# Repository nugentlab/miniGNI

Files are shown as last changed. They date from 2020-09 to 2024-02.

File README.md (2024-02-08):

## [An updated version of the miniGNI can be found here](https://github.com/klackerman00/miniGNI_plus)
# miniGNI Version 1.0
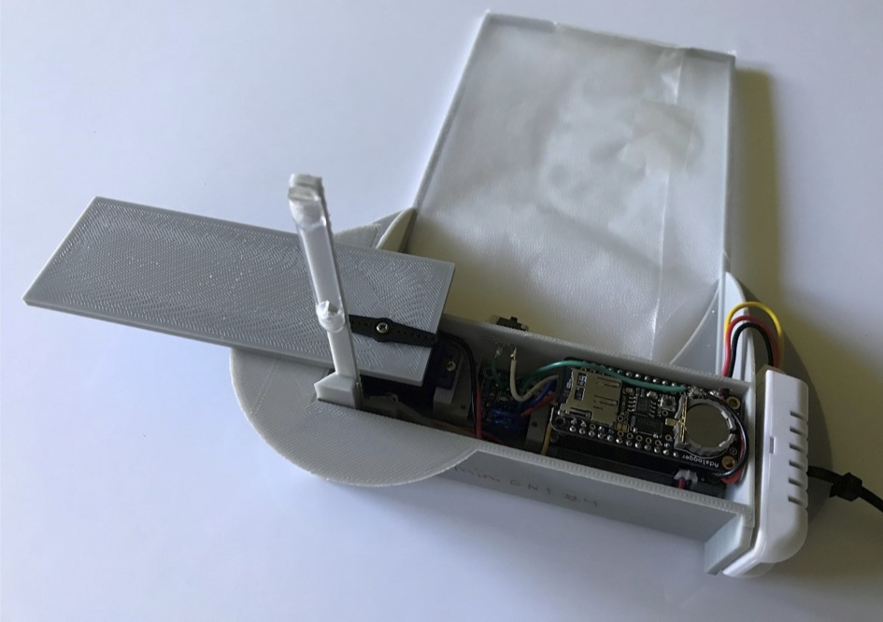
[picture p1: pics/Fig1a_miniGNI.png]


## **mini-GNI** - Miniature Giant Nucleus Impactor 

The mini-GNI is a small, 3D instrumentation created by the [Nugent Research Group](http://alisonnugent.com/) used to sample sea salt aerosol (SSA) aloft using ground-based platforms. Modeled off the [National Center for Atmospheric Research GNI](https://www.eol.ucar.edu/instruments/giant-nuclei-impactor), the mini-GNI combines Arduino based microcontrollers and 3D printed technology in order to expose polycarbonate slides to free airstreams, allowing SSA to impact onto them. Then, these slides are analyzed in by NCAR's GNI microscope to calculate aerosol particle size distributions. Information on the methods behind the miniGNI can be found in this paper: 

> A New Instrument for Determining the Coarse-Mode Sea Salt Aerosol Size Distribution - [Taing et al., 2021](https://journals.ametsoc.org/view/journals/atot/38/11/JTECH-D-20-0197.1.xml)

while the microscope methods are explained in this paper: 

> The Giant Nucleus Impactor (GNI)—A System for the Impaction and Automated Optical Sizing of Giant Aerosol Particles with Emphasis on Sea Salt. Part I: Basic Instrument and Algorithms - [Jensen et al., 2020](https://journals.ametsoc.org/view/journals/atot/37/9/jtechD190109.xml?rskey=7VVZ45&result=6)

Additional information about the observations gathered by the miniGNI V1.0 are in this corresponding paper: 

> Mechanisms controlling giant sea salt aerosol size distributions along a tropical orographic coastline - [Ackerman et al., 2023](https://acp.copernicus.org/articles/23/13735/2023/)

### Mini-GNI Repository 

The mini-GNI repository is composed of several folders containing different python processing scripts.

To download this repository from GitHub, run:

```
  git clone https://github.com/nugentlab/miniGNI
```

To just download them individual parts and refer to the context in which the scripts are used, please refer to the appropriate subsection. 

## 1. Construct your own Mini-GNI
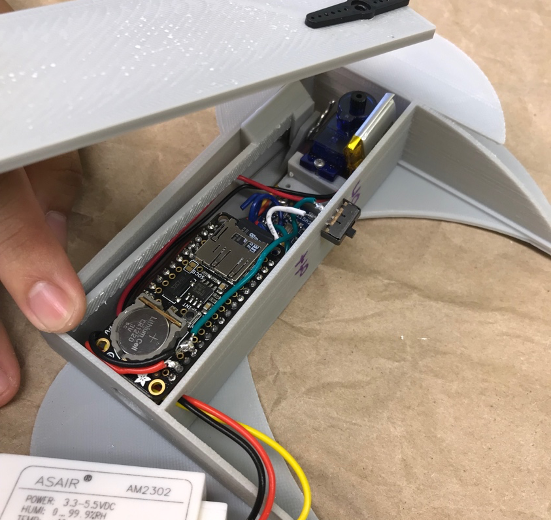
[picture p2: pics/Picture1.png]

This directory provides the information necessary to create your own mini-GNI. It's contents are filled with all of the STL files necessary for 3-D printing, in addition to the coding for the arduino microcontroller within the mini-GNI and the arduino within the base controller (the controller used to connect with the mini-GNI while it is aloft). An assembly diagram is provided as well. 

To download this directory from GitHub, run:

```
  git clone https://github.com/nugentlab/miniGNI/miniGNI_Assembly
```

## 2. Mini-GNI Sample Anaylsis Preperation

Once the mini-GNI has been used to sample (more specific details on sampling methodology here *insert link to paper*), code needs to be run to compile environment files for use in analysis by the microscope. The miniGNI_functions.py creates functions used by the environment_file_generator.py that compile the information obtained by the miniGNI sensors along with measurements that were obtained by the acting scientist (i.e. wind speeds). These environment files are generated for each sample obtained, and rely on the manual input of wind speed.

To download only this directory from GitHub, run:

```
  git clone https://github.com/nugentlab/miniGNI/miniGNI_Analysis_Code
```

## 3. Mini-GNI Post-Processing  

Now that the slides have been analysed by the NCAR microscope, their data comes back as dry salt radii in bins of 0.2 microns. These can be processed efficiently using the codes below and compiled into a CSV file to be read by Python's Pandas package. Additinoally, extra code for downloading wave information from local buoys is also included. 

To download only this directory from GitHub, run:

```
  git clone https://github.com/nugentlab/miniGNI/SSA_Analysis 
```

## 4. SSA Anaylsis Scripts for Easy Variable Comparison

The final scripts include all of the functions used in analyzing the CSV files that contained all relevant information to the SSA sizes, concentratrions and distributions. These scripts contain straight forward plots that allow for interchangable variables for the x, y, and z axes. 

To download only this directory from GitHub, run:

```
  git clone https://github.com/nugentlab/miniGNI/SSA_Plot_Codes
```

#### Ranz-Wong Code Reference

This folder contains original code and information used to calculate the collision efficiency developed by Ranz and Wong in 1952.

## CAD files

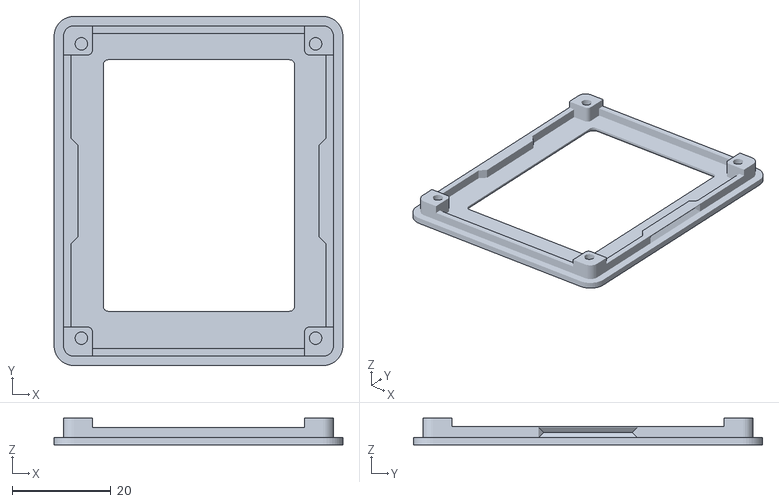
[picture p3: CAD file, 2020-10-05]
miniGNI_Assembly/feather-tft-top.stl
58.6 x 70.8 x 5.40

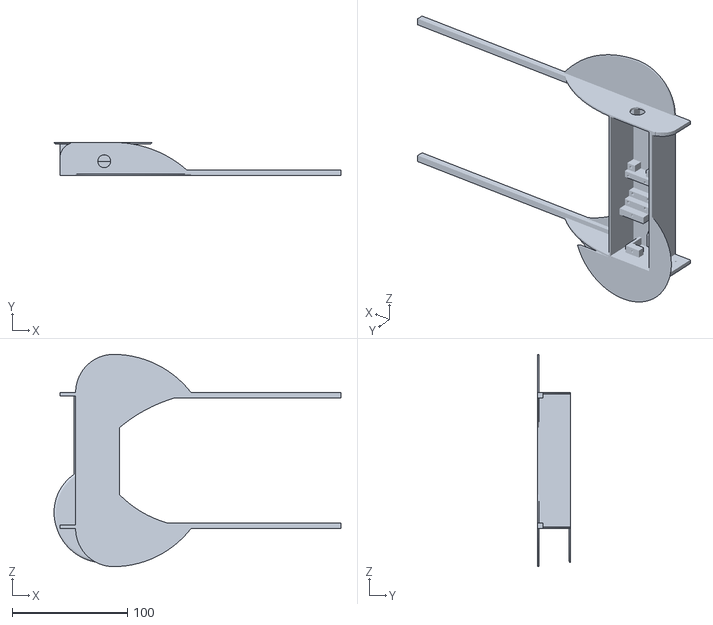
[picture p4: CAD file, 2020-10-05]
miniGNI_Assembly/base_ext.stl
248.7 x 28.7 x 184.0

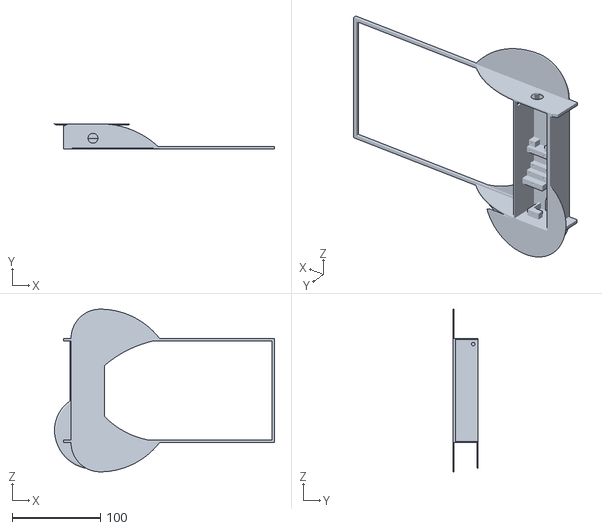
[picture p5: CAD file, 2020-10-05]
miniGNI_Assembly/hingebase_v5.stl
248.7 x 28.7 x 184.0

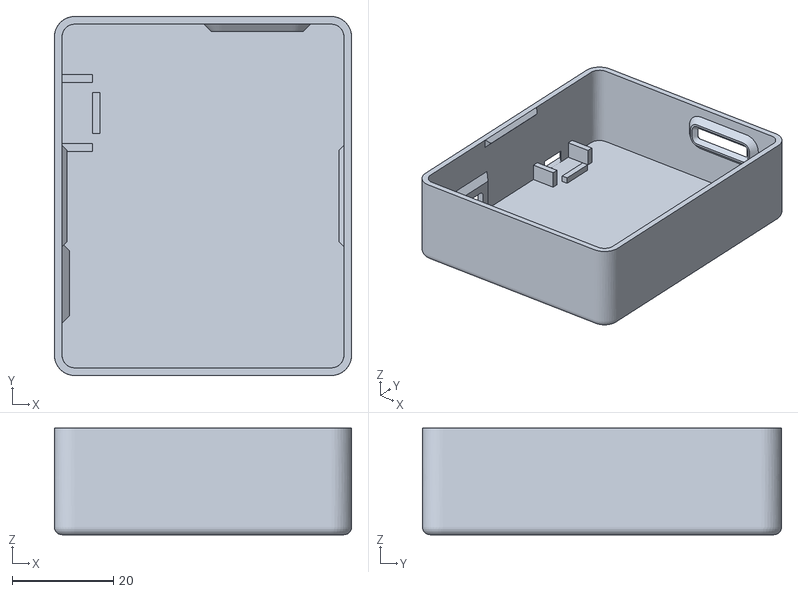
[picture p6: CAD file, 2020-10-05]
miniGNI_Assembly/feather-tft-case.stl
58.6 x 70.8 x 21.0

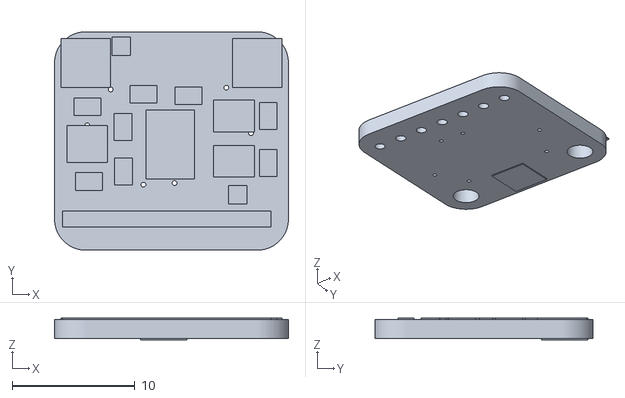
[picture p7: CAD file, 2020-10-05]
miniGNI_Assembly/barometer.stl
19.0 x 17.8 x 1.77

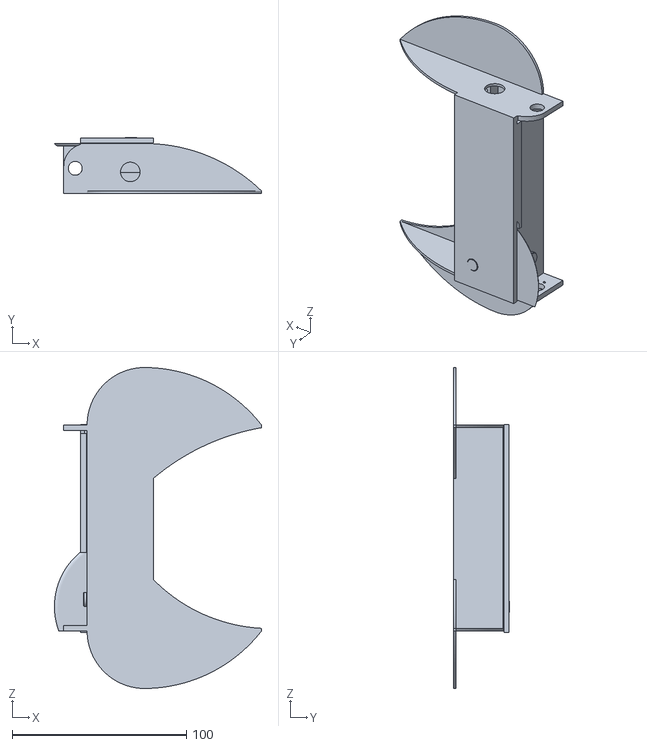
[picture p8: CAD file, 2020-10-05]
miniGNI_Assembly/hk_3.stl
118.7 x 32.2 x 184.0

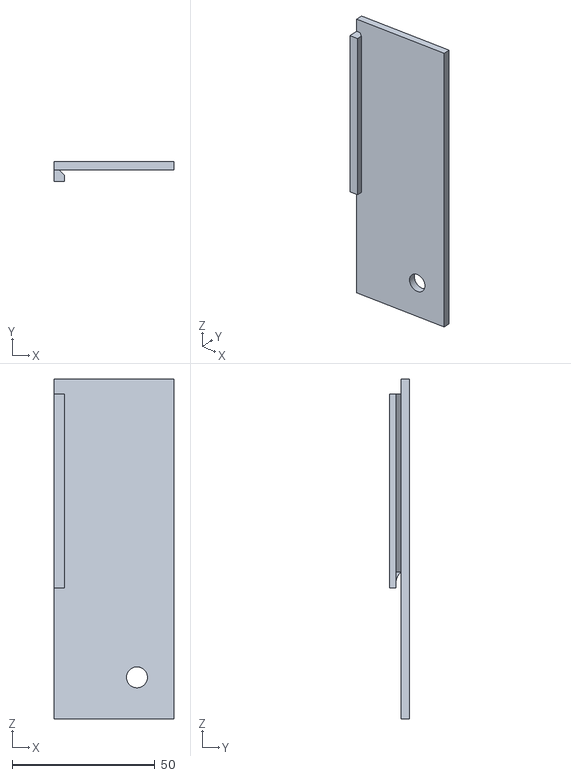
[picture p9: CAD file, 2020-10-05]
miniGNI_Assembly/door_v2.stl
41.9 x 7.12 x 119.1

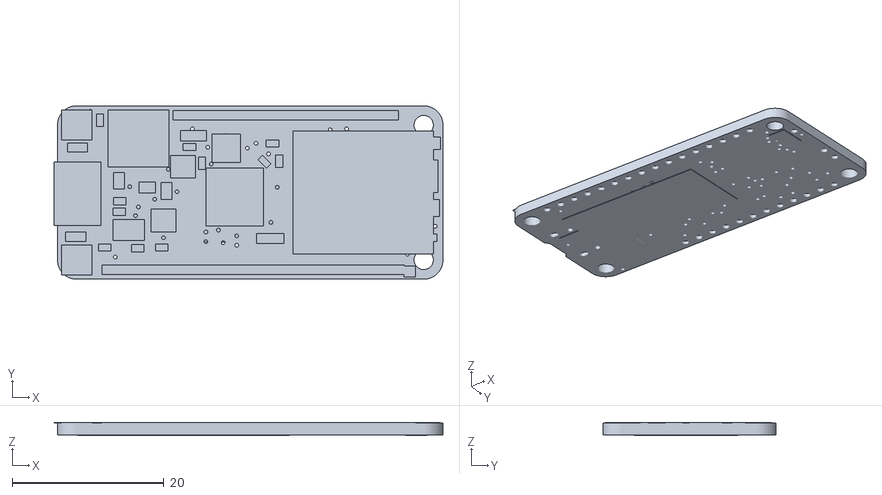
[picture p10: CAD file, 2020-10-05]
miniGNI_Assembly/feather.stl
51.3 x 22.9 x 1.77

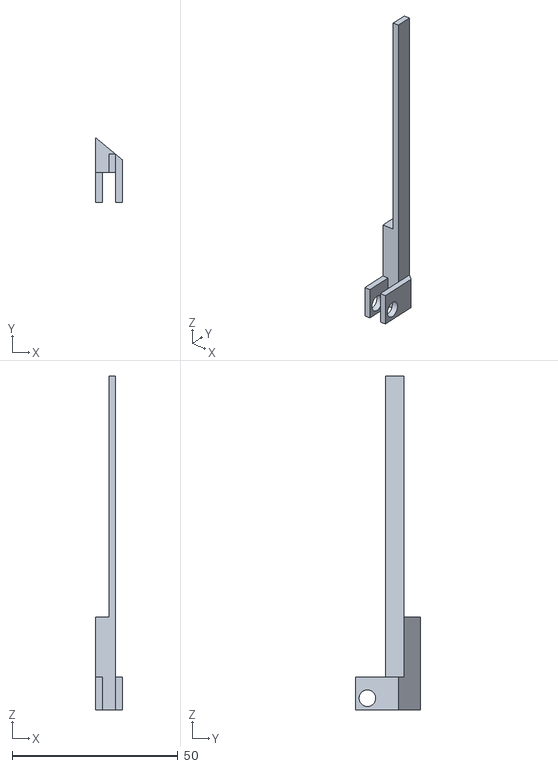
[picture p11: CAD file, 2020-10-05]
miniGNI_Assembly/arm.stl
8.01 x 19.4 x 100.7

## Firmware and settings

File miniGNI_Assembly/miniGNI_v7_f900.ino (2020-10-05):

//
// Firmware for the mini-GNI unit.
// Version 7 
// Frequency: 900 MHz
// v2  --  10/01/2018  Changed the myservo.attach() calls to happen right before we want to move the servo. This prevents
//                     the servo from moving right when the unit is powered on. 
// v5  --  04/01/2019  Added support for the 9-DOF orientation sensor and made it compatible with v5 of the base station
// v5a --  04/10/2019  Added support for the AM-2302 temperature humidity sensor (DHT22 type)
// v6a --  04/11/2019  Removed ability of control station v5a to receive from multiple-GNIs because it doesn't work
// v7  --  07/26/2019  Added comments and fixed organization


//Modes: define the features that are connected:
//#define USE_SERIAL      // use the serial port...only do this if plugged into a computer!
#define USE_WIRELESS    // Talk over the RFM95 LoRa Radio (adafruit id# 3178)
#define USE_BARO        // Use the MPL3115A2 pressure/altitude/temperature sensor (adafruit id# 1893)
#define USE_SD          // Use the SD card and real time clock (adafruit id# 2922)
#define USE_DOF         // Use the 9-DOF orientation sensor (adafruit id# 2472)
#define USE_DHT         // Use the AM-2302 temperature/humidity sensor (adafruit id# 393)

#include <SPI.h>
#include <Wire.h>
#include <Servo.h>


//pinouts:
#define SERVO_PIN 9 
#define SD_CHIP_SELECT 10
#define RFM95_CS 8
#define RFM95_RST 4
#define RFM95_INT 3
#define DHTPIN 6


//radio
#ifdef USE_WIRELESS
  #include <RH_RF95.h>
  #define RF95_FREQ 900.0 //change this depending on what mini-GNI + control station pair
  RH_RF95 rf95(RFM95_CS, RFM95_INT);
  int16_t packetnum = 0;  // packet counter, we increment per xmission
#endif


//temperature humidity sensor
#ifdef USE_DHT
  #include "DHT.h"
  #define DHTTYPE DHT22
  DHT dht(DHTPIN, DHTTYPE);
#endif


//9-DOF sensor
#ifdef USE_DOF
  #include <Adafruit_Sensor.h>
  #include <Adafruit_BNO055.h>
  #include <utility/imumaths.h>
  Adafruit_BNO055 bno = Adafruit_BNO055();
#endif


//barometer
#ifdef USE_BARO
  #include <Adafruit_MPL3115A2.h>
  Adafruit_MPL3115A2 baro = Adafruit_MPL3115A2();
#endif


//sd card and rtc
#ifdef USE_SD
  #include <SD.h>
  #include "RTClib.h"
  RTC_PCF8523 rtc;
  File logfile;
#endif


//servo motor position
Servo myservo;
int pos = 0;            // variable to store the servo position
bool door_status = 0;   // 0:closed, 1:open


void setup() 
{
  String setup_error = "NONE";
  pinMode(SERVO_PIN, OUTPUT);

  #ifdef USE_DHT
    dht.begin();
  #endif
  
  #ifdef USE_SERIAL
    Serial.begin(115200);
    while (!Serial) { delay(1); } // wait!
    Serial.println("MiniGNI");
    Serial.println();
  #endif

  #ifdef USE_WIRELESS
    pinMode(RFM95_RST, OUTPUT);
    digitalWrite(RFM95_RST, HIGH);
    digitalWrite(RFM95_RST, LOW);
    delay(10);
    digitalWrite(RFM95_RST, HIGH);
    delay(10);
    if(!rf95.init()) {
      setup_error = "RF INIT";
    }
    if (!rf95.setFrequency(RF95_FREQ)) {
      setup_error = "RF FREQ";
    }
  #endif  

  #ifdef USE_BARO
    if (! baro.begin()) {
      setup_error = "BARO INIT";
    }
  #endif

  #ifdef USE_DOF
    if(!bno.begin()){
      setup_error = "DOF INIT";
    }
  #endif
  
  #ifdef USE_SD
    if ( !rtc.initialized()) {
      Serial.println("RTC is NOT running! Setting now");
      rtc.adjust(DateTime(F(__DATE__), F(__TIME__))); //sets the RTC to the date & time this sketch was compiled
    }
    if (!SD.begin(SD_CHIP_SELECT)) {
      Serial.println("Card init. failed!");
    }
    char filename[15];
    strcpy(filename, "ANALOG00.TXT");
    for (uint8_t i = 0; i < 100; i++) {
      filename[6] = '0' + i/10;
      filename[7] = '0' + i%10;
      if (! SD.exists(filename)) {
        break;
      }
    }
  #endif
  
  myservo.attach(SERVO_PIN);
  myservo.write(180); //start closed!
  delay(2000); //wait for the movement
  myservo.detach();
  
}


int lenMicroSecondsOfPeriod = 20 * 1000; // 20 milliseconds (ms)
int closedPosition = 1.0 * 1000; // 1.0 ms is 0 degrees
int openPosition = 2.0 * 1000; // 2.0 ms is 180 degrees


void loop() {
  delay(1000);
  char message_save[65];
  char message_send[19];

  char open_command[20];
  char close_command[20];

  sprintf(open_command, "OPEN %02d",1);
  sprintf(close_command, "CLOSE %02d",1);

  int Year   = 0;
  int Month  = 0;
  int Day    = 0;
  int Hour   = 0;
  int Minute = 0;
  int Second = 0;
  int altm_int  = 0;
  int tempC_int = 0;
  int presP_int = 0;
  int rhDH_int = 0;
  int tempDH_int = 0;
  
  float x_deg = 0;
  float y_deg = 0;
  float z_deg = 0;
  
  #ifdef USE_SD
    DateTime now = rtc.now();
    Year   = now.year();
    Month  = now.month();
    Day    = now.day();
    Hour   = now.hour();
    Minute = now.minute();
    Second = now.second();
  #endif

  //read in the DH22 temperature and humidity
  #ifdef USE_DHT
    float rhDH = dht.readHumidity();
    float tempDH = dht.readTemperature();
    rhDH_int = round(100*rhDH);
    tempDH_int = round(100*tempDH);
  #endif

  //read in the altitude and temperature
  #ifdef USE_BARO
    float altm  = baro.getAltitude();
    float tempC = baro.getTemperature();
    float presP = baro.getPressure();
    altm_int  = round(100*altm);
    tempC_int = round(100*tempC);
    presP_int = round(100*presP);
  #endif

  //read orientation from the 9-DOF
  #ifdef USE_DOF
    sensors_event_t event;
    bno.getEvent(&event);
    x_deg = event.orientation.x;
    y_deg = event.orientation.y;
    z_deg = event.orientation.z;
  #endif 

  //create a message to save to SD card and another message to send via radio
  sprintf(message_save, "%04d%02d%02dT%02d%02d%02d,%06d,%04d,%06d,%04d,%04d,%1d,%2.2f,%2.2f,%2.2f",Year,Month,Day,Hour,Minute,Second,altm_int,tempC_int,presP_int,rhDH_int,tempDH_int,door_status,x_deg,y_deg,z_deg);
  sprintf(message_send, "%06d,%04d,%04d,%1d",altm_int,rhDH_int,tempDH_int,door_status);

  #ifdef USE_SERIAL    
    Serial.println(message_save);
  #endif
  
  #ifdef USE_SD
    digitalWrite(8,HIGH);
    delay(100);
    File logfile = SD.open("datalog.csv", FILE_WRITE);
    logfile.println(message_save);
    logfile.close();
    digitalWrite(8,LOW);
    Serial.println("Transmitting..."); // Send a message to rf95_server  
    Serial.print("Sending "); Serial.println(message_send);
    Serial.println("Sending...");
    delay(10);
   #endif

   #ifdef USE_WIRELESS
      message_send[18] = 0;
      rf95.send((uint8_t *)message_send,21);
      delay(10);
      rf95.waitPacketSent();
      // Now wait for a reply
      uint8_t buf[RH_RF95_MAX_MESSAGE_LEN];
      uint8_t len = sizeof(buf);
      if (rf95.waitAvailableTimeout(1000))
      { 
        // Should be a reply message for us now   
       if (rf95.recv(buf,&len))
       {
          Serial.print("Got reply: ");
          Serial.println((char*)buf);
          Serial.print("RSSI: ");
          Serial.println(rf95.lastRssi(), DEC);
          if( strcmp( (char*)buf ,open_command) == 0){
            myservo.attach(9);
            for (pos = 180; pos >= 0; pos -= 1) { // goes from 180 degrees to 0 degrees
              myservo.write(pos);                 // tell servo to go to position in variable 'pos'
              delay(15);                          // waits 15ms for the servo to reach the position
            }
            myservo.detach();
            door_status = 1;
          }
          if( strcmp( (char*)buf ,close_command) == 0){
            myservo.attach(9);
            for (pos = 0; pos <= 180; pos += 1) { 
              myservo.write(pos);              
              delay(15);                       
            }
            door_status = 0;
            delay(1000);
            myservo.detach();
          }
        }
        else
        {
          Serial.println("Receive failed");
        }
      }
      else
      {
      }
  #endif
}

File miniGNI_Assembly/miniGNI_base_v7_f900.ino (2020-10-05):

//
//  for the mini-GNI control station
//  Version 7
//  Frequency: 900 MHz
//  v5  --              Added ability to receive from multiple mini-GNI v5 units
//                      and minor edits
//  v6a --  04/11/2019  Removed the v5 function to receive from multiple mini-GNI
//                      v5 units but kept minor edits.
//  v7  --  07/26/2019  Minor edits adding comments and fixing structure


//#define USE_SERIAL //comment this out if not using the serial stream

#include <SPI.h>
#include <RH_RF95.h>
#include <Wire.h>
#include <Adafruit_GFX.h>    // Core graphics library
#include <Adafruit_ILI9341.h> // Hardware-specific library
#include <Adafruit_STMPE610.h> //touchscreen
 
#define RFM95_CS 8
#define RFM95_RST 4
#define RFM95_INT 3
#define RF95_FREQ 900.0 //change according to mini-GNI + control station pair
 
RH_RF95 rf95(RFM95_CS, RFM95_INT);

#define LED 13

#define STMPE_CS 6
#define TFT_CS   9
#define TFT_DC   10
#define SD_CS    5

// This is calibration data for the raw touch data to the screen coordinates
#define TS_MINX 3800
#define TS_MAXX 100
#define TS_MINY 100
#define TS_MAXY 3750

Adafruit_ILI9341 tft = Adafruit_ILI9341(TFT_CS, TFT_DC);
Adafruit_STMPE610 ts = Adafruit_STMPE610(STMPE_CS);
 
void setup()
{
  pinMode(LED, OUTPUT);
  pinMode(RFM95_RST, OUTPUT);
  digitalWrite(RFM95_RST, HIGH);

  #ifdef USE_SERIAL
    Serial.begin(115200);
    while (!Serial) { delay(1); }
    delay(100);
    Serial.println("Mini GNI base station v05!");
  #endif
 
  // manual reset
  digitalWrite(RFM95_RST, LOW);
  delay(10);
  digitalWrite(RFM95_RST, HIGH);
  delay(10);
 
  while (!rf95.init()) {
    #ifdef USE_SERIAL
      Serial.println("LoRa radio init failed");
    #endif
    while (1);
  }
  #ifdef USE_SERIAL
    Serial.println("LoRa radio init OK!");
  #endif
   
  if (!rf95.setFrequency(RF95_FREQ)) {
    #ifdef USE_SERIAL
      Serial.println("setFrequency failed");
    #endif
    while (1);
  }
  #ifdef USE_SERIAL
    Serial.print("Set Freq to: "); Serial.println(RF95_FREQ);
  #endif
   
  rf95.setTxPower(23, false);  //5 to 23

  if (!ts.begin()) {
    #ifdef USE_SERIAL
      Serial.println("Couldn't start touchscreen controller");
    #endif
    while (1);
  }
  
  #ifdef USE_SERIAL
    Serial.println("Touchscreen started");
  #endif
  
  tft.begin();
  yield();
  tft.fillScreen(ILI9341_BLACK);
  yield();
  tft.drawRect(0, 0, 240, 40, ILI9341_BLUE);
  tft.setCursor(18,8);
  tft.setTextColor(ILI9341_WHITE);
  
  tft.setTextSize(3);
  tft.println("Mini GNI v7");
  
  tft.drawRect(15,220,95,60,ILI9341_BLUE);
  tft.fillRect(15,220,95,60,ILI9341_BLUE);
  tft.setCursor(25,240);
  tft.println("OPEN");

  tft.drawRect(130,220,95,60,ILI9341_BLUE);
  tft.fillRect(130,220,95,60,ILI9341_BLUE);
  tft.setCursor(135,240);
  tft.println("CLOSE");

  tft.setTextColor(ILI9341_WHITE,ILI9341_BLACK);

}

char user_input = 'n';
char outgoing_message[20] = "ACK";

void loop(){
  
  #ifdef USE_SERIAL
    if(Serial.available()){
      user_input = Serial.read();
      Serial.println(user_input);
    }
  #endif

  digitalWrite(LED, LOW);
  digitalWrite(RFM95_CS, HIGH);
  
  TS_Point p;
  while (ts.touched()) {
    while (! ts.bufferEmpty()) {
      p = ts.getPoint();
      p.x = map(p.x, TS_MINX, TS_MAXX, 0, tft.width());
      p.y = map(p.y, TS_MINY, TS_MAXY, 0, tft.height());
      //true_y = tft.height() -  map(p.x, TS_MINX, TS_MAXX, 0, tft.height());
      //true_x = map(p.y, TS_MINY, TS_MAXY, 0, tft.width());
      
    }
    ts.writeRegister8(STMPE_INT_STA, 0xFF); // reset all ints
  }

  if( (p.y > 210) && (p.y < 270) && (p.x > 15) && (p.x < 110) ){
    user_input = 'o';
    tft.fillRect(15,220,95,60,ILI9341_WHITE);
    tft.setTextColor(ILI9341_BLACK,ILI9341_WHITE);
    tft.setCursor(25,240);
    tft.println("OPEN");
  }
  if( (p.y > 210) && (p.y < 270) && (p.x > 130) && (p.x < 225) ){
    user_input = 'c';
    tft.fillRect(130,220,95,60,ILI9341_WHITE);
    tft.setTextColor(ILI9341_BLACK,ILI9341_WHITE);
    tft.setCursor(135,240);
    tft.println("CLOSE");
  }
  
  digitalWrite(RFM95_CS, LOW);
  delay(20);
  
  if (rf95.available()){
    uint8_t buf[RH_RF95_MAX_MESSAGE_LEN];
    uint8_t len = sizeof(buf);
    if (rf95.recv(buf, &len)){
      digitalWrite(LED, HIGH);
      #ifdef USE_SERIAL
        Serial.print((char*)buf);
        Serial.print(", RSSI: ");
        Serial.println(rf95.lastRssi(), DEC);
      #endif

        tft.setTextColor(ILI9341_WHITE,ILI9341_BLACK);
        tft.setCursor(20,60);
        tft.print("ALT: ");
        printPart(buf,0,4);
        tft.setCursor(20,100);
        tft.print("TEMP: ");
        printPart(buf,12,2);
        tft.print(".");
        printPart(buf,14,1);
        tft.setCursor(20,140);
        tft.print("RH:   ");
        printPart(buf,7,2);
        tft.print(".");
        printPart(buf,9,1);
        tft.setCursor(20,180);
        tft.print("DOOR: ");
        if( buf[17] == '1'){
          tft.print("OPEN  ");
        }
        if( buf[17] == '0'){
          tft.print("SHUT");
        }
    }
  }

  if( user_input != 'n'){
    if( user_input == 'o'){
      #ifdef USE_SERIAL
        Serial.println("opening door!");
      #endif
      //strncpy((char*)outgoing_message, "OPEN DOOR", 20);
      sprintf(outgoing_message,"OPEN %02d",1);
    }
    if( user_input == 'c'){
      #ifdef USE_SERIAL
        Serial.println("closing door!");
      #endif
      sprintf(outgoing_message,"CLOSE %02d",1);
      //strncpy((char*)outgoing_message, "CLOSE DOOR", 20);
    }
    #ifdef USE_SERIAL
      Serial.println( (char*)outgoing_message);
    #endif
      
    //rf95.send(outgoing_message, sizeof(outgoing_message));
    rf95.send((uint8_t *)outgoing_message, 20);
    rf95.waitPacketSent();
    user_input = 'n';

    tft.fillRect(15,220,95,60,ILI9341_BLUE);
    tft.setTextColor(ILI9341_WHITE,ILI9341_BLUE);
    tft.setCursor(25,240);
    tft.println("OPEN");
    tft.fillRect(130,220,95,60,ILI9341_BLUE);
    tft.setTextColor(ILI9341_WHITE,ILI9341_BLUE);
    tft.setCursor(135,240);
    tft.println("CLOSE");
  }
  
}

void printPart(uint8_t* txt, byte start, byte len){
  for(byte i = 0; i < len; i++){
    tft.write(txt[start + i]);
  } 
}
